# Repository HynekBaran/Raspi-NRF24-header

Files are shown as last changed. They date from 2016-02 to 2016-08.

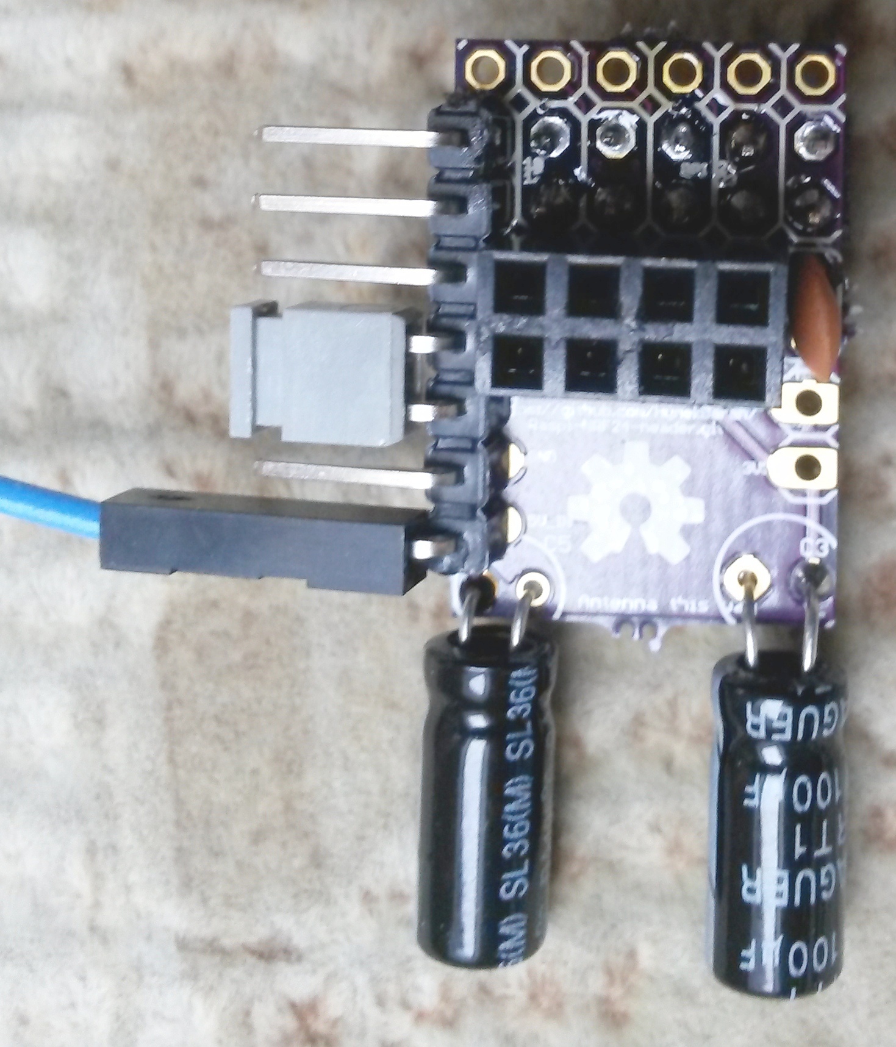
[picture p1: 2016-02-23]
photos/20160223_103329.jpg

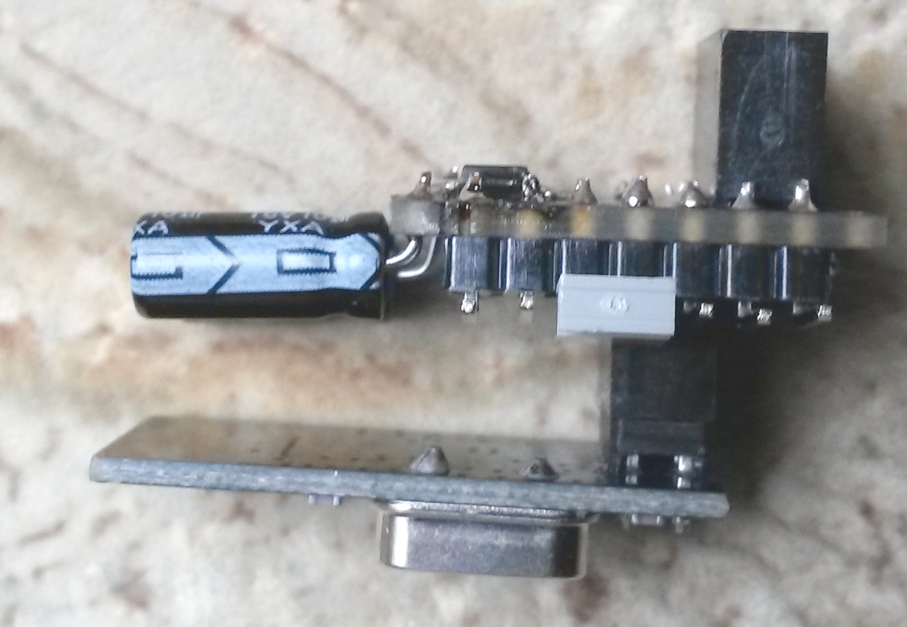
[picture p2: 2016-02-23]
photos/20160223_103441.jpg

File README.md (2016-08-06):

# Raspi-NRF24-header
Raspberry Pi NRF24L01 header (incl. 5V to 3V3 voltage regulator and additional SPI header)

This PCB is modified version of
https://www.openhardware.io/view/17/Raspberry-Pi2-GPIO-interface-for-NRF24L01.

####Usage with MySensors
May be used as MySensors.org gateway, see
https://github.com/mysensors/Raspberry
for details.

#####Installation of MySensor's gateway
``` bash
 # NRF24 Libraries
 apt install git make g++ rsyslog
 git clone "https://github.com/TMRh20/RF24.git"
 cd RF24/
 make all
 cd ..
 # MySensor gateway for Raspberry Pi
 git clone "https://github.com/mysensors/Raspberry.git"
 cd Raspberry/
 make all
 sudo make install
 sudo make enable-gwserial
 ```
 
#####Usage
 
 Make your gateway available as `/dev/ttyMySensorsGateway` by running
 ```bash
 sudo make enable-gwserial
 ```

 If accesing by some software controller, it has to have an access rights to above device.
 E.g., when using FHEM controller, allow it to access /dev/ttyMySensorsGateway by
``` bash
 usermod -a -G tty fhem
 ```
 
####PWR_SEL jumper (must be shorted correctly)
Select power source by connecting a jumper to the proper pair of pins:
```
Short 3V3_NRF <---> 3V3PI  if using Raspberry's internal 3V3 (take care!)
Short 3V3_NRF <---> 3V3EXT if assembled LD117 regulator 
                              and feed the device via EXT_PWR_IN 5V pin (e. g. connected to Raspi 5V)
```
Without a proper short/jumper described above, radio is not powered!

####PWR_OUT1, PWR_OUT2 headers (optional)
PWR_OUT1, PWR_OUT2 headers may be used to feed any optional external 3.3 V device



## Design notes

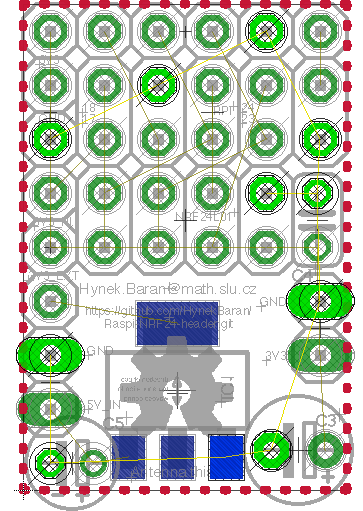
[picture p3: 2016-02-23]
RaspNRF24.brd.png

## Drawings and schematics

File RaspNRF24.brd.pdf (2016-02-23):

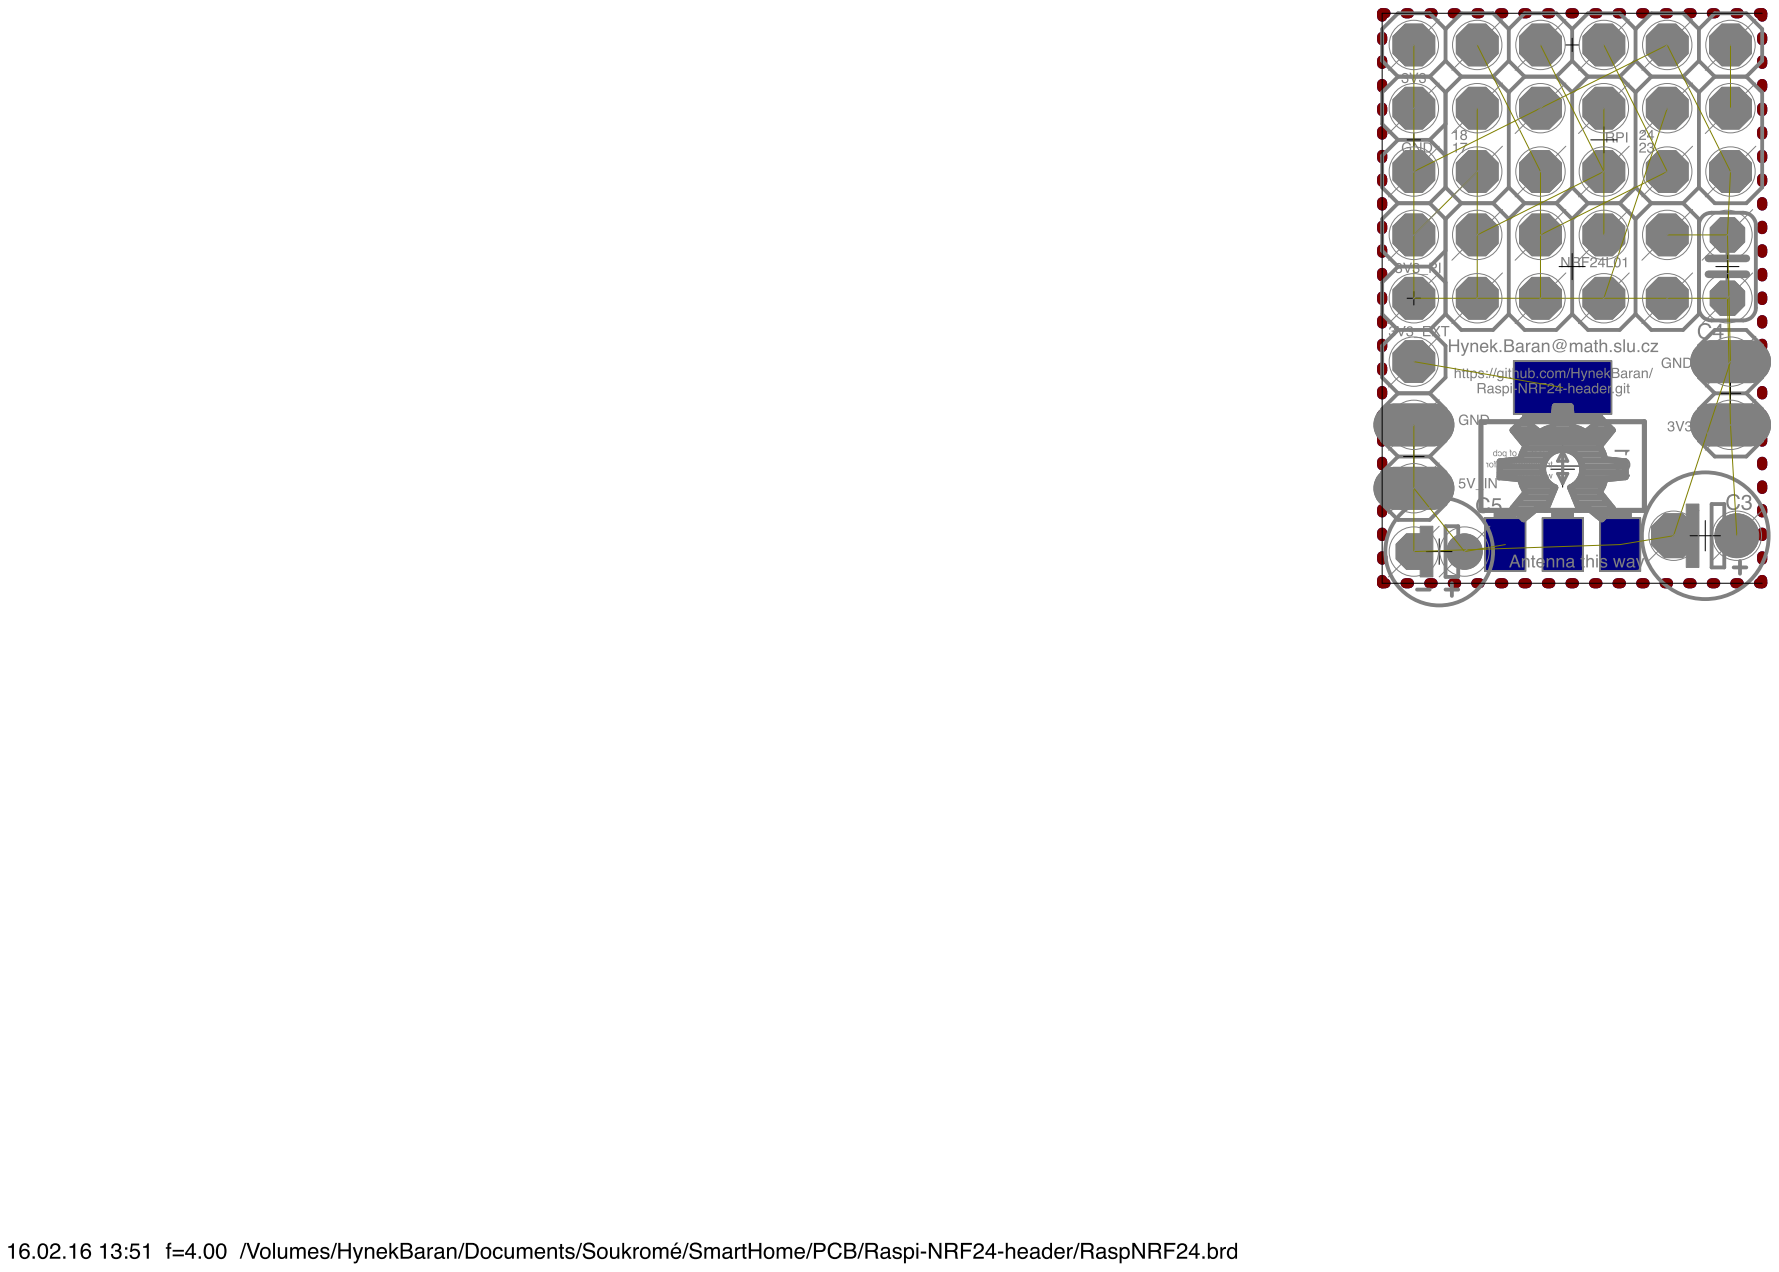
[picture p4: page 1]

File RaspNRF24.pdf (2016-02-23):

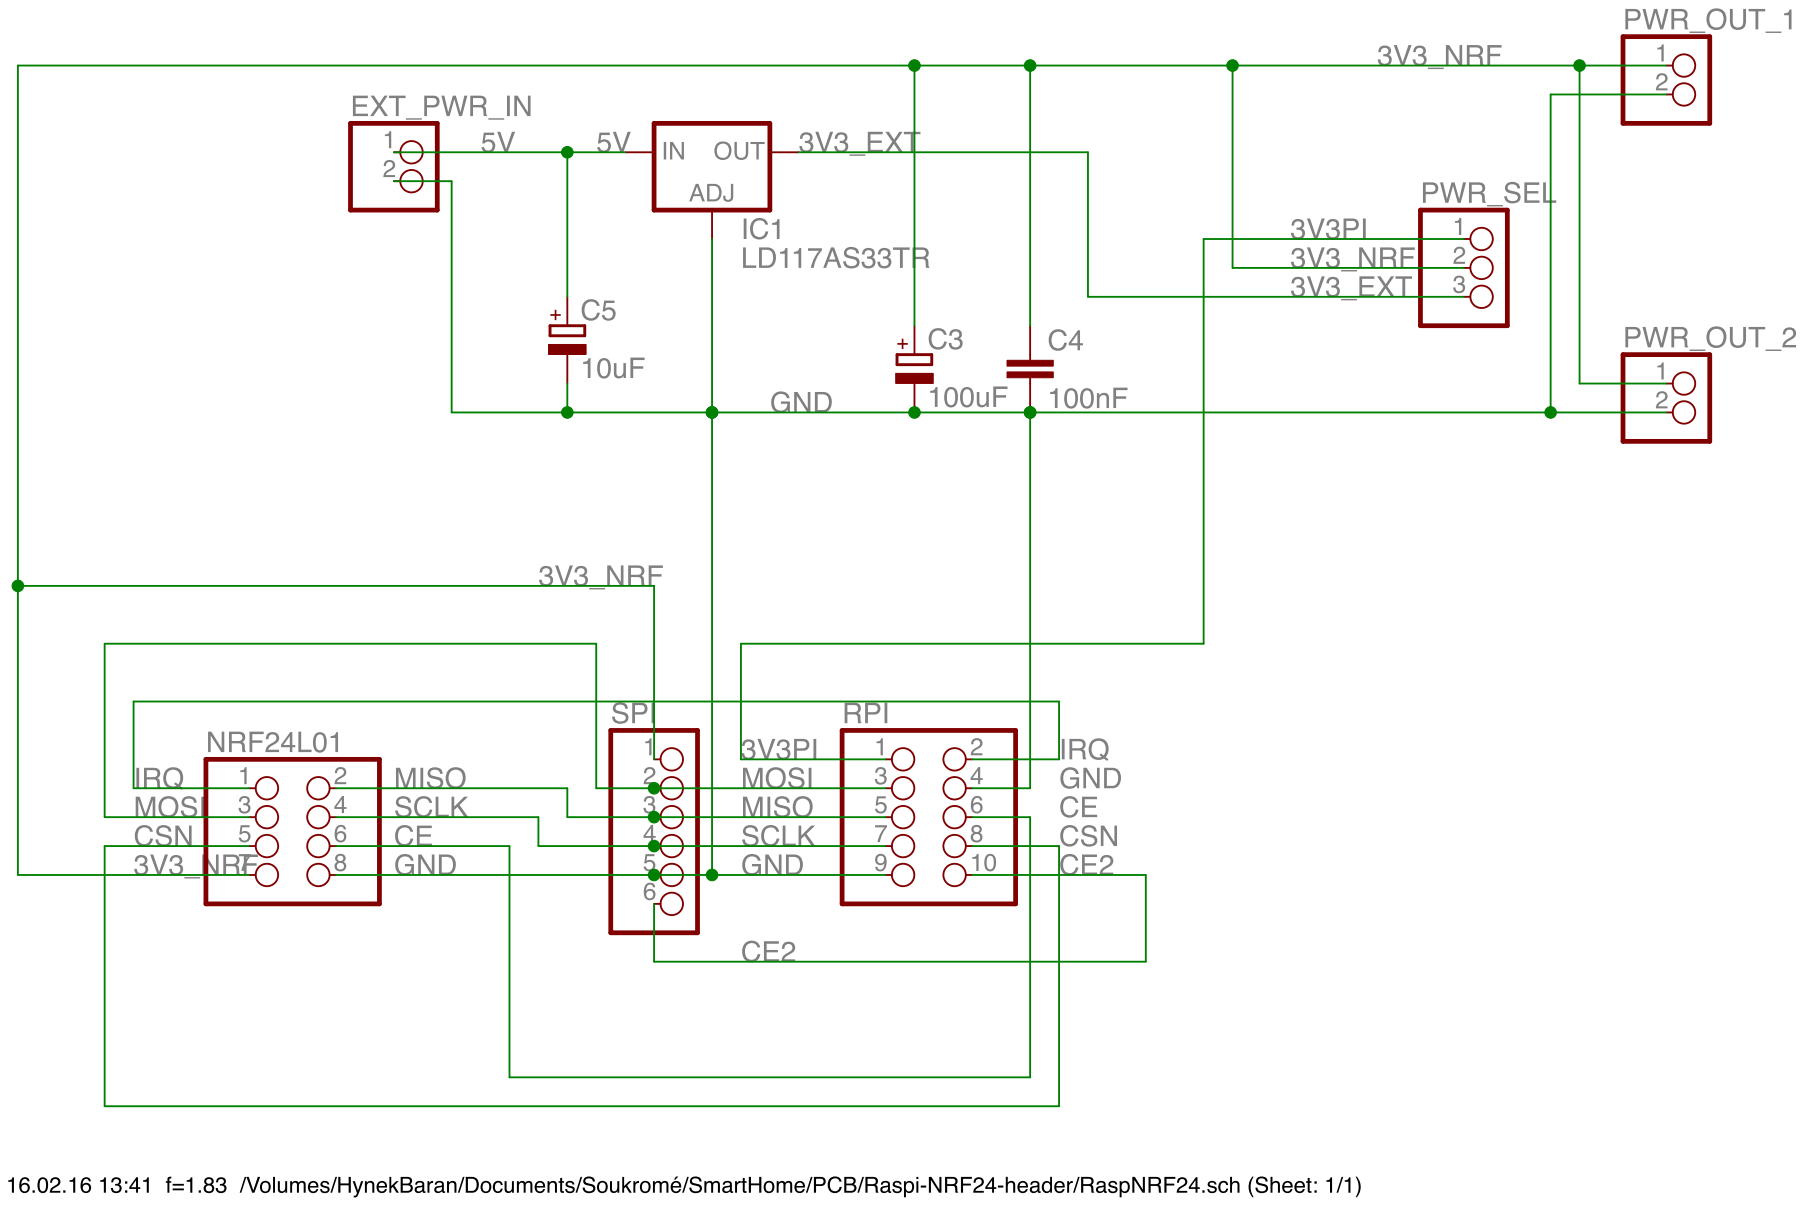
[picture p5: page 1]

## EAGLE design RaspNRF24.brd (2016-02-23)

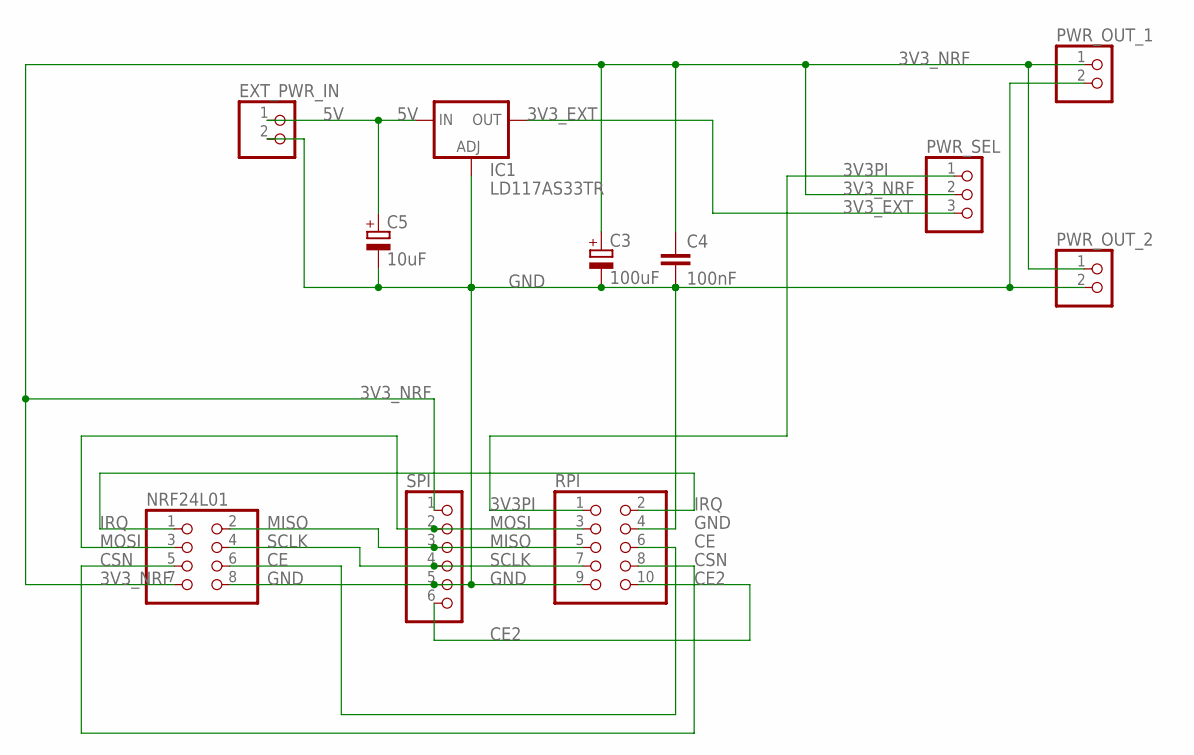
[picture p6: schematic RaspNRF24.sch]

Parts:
C3: 100uF; E2,5-5
C4: 100nF; C025-024X044
C5: 10uF; E2-4
EXT_PWR_IN: PINHD-1X2; 1X02
IC1: LD117AS33TR; SOT223
NRF24L01: PINHD-2X4; 2X04
PWR_OUT_1, PWR_OUT_2: PINHD-1X2; 1X02
PWR_SEL: PINHD-1X3; 1X03
RPI: PINHD-2X5; 2X05
SPI: PINHD-1X6; 1X06

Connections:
3V3PI: PWR_SEL.1, RPI.1
3V3_EXT: IC1.4 (OUT), PWR_SEL.3
3V3_NRF: C3.+, C4.1, NRF24L01.7, PWR_OUT_1.1, PWR_OUT_2.1, PWR_SEL.2, SPI.1
5V: C5.+, EXT_PWR_IN.1, IC1.3 (IN)
CE: NRF24L01.6, RPI.6
CE2: RPI.10, SPI.6
CSN: NRF24L01.5, RPI.8
GND: C3.-, C4.2, C5.-, EXT_PWR_IN.2, IC1.1 (ADJ), NRF24L01.8, PWR_OUT_1.2, PWR_OUT_2.2, RPI.4, RPI.9, SPI.5
IRQ: NRF24L01.1, RPI.2
MISO: NRF24L01.2, RPI.5, SPI.3
MOSI: NRF24L01.3, RPI.3, SPI.2
SCLK: NRF24L01.4, RPI.7, SPI.4

Board: 2 copper layers, 12 parts (1 on the bottom side), 12 nets, no tracks yet.

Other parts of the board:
U$1: OSHWLOGO_TOL_0.2

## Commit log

2016-01-26 Ordered on OHSpark.com https://oshpark.com/shared_projects/ncBBwenI
    [RaspNRF24.brd, RaspNRF24.sch]
2016-02-23 Schemas and photos added.
    [RaspNRF24.brd]
